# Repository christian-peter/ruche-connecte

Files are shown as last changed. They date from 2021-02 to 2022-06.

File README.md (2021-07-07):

# !!! EN COURS DE REDACTION !!! 
donc incomplet et en évolution à un rythme aléatoire

# Outil de suivi de ruchers
Ce projet est en cours de développement. Tous les éléments décrits dans le synoptique ne sont donc pas fonctionnels à ce jour.

Certains éléments ont été développés par des apprentis ingénieurs suivant la formation "électronique et informatique industrielle" à 
[Polytech Nice Sophia](http://unice.fr/polytechnice/fr). Une page spécifique à ce projet est disponible [ici](http://rucher.polytech.unice.fr/).  

L'objectif consiste à relever différents paramètres (masse, vibrations, température et hygrométrie interne à la ruche, données météorologiques) pour les rendre accessibles à distance via des périphériques tels qu'un ordinateur, une tablette, un smartphone ....  
 
Afin de remplir ces différentes fonctions, le système global à été scindé en plusieurs blocs. Les fonctions des trois premiers modules, qui doivent être autonomes en énergie, sont les suivantes :

* relever la masse de la ruche ;
* mesurer les grandeurs internes (températures, hygrométrie, vibrations, ....) ;
* mesurer les données météorologiques (température, hygrométrie, vent, pluie, ensoleillement, ...).

Les données relevées par ces modules sont transmises via un réseau LoRa, dont la portée doit être importante, à une passerelle dont la fonction consiste à enregistrer ces mesures dans une base de données. Ces données sont alors rendues accessibles via un serveur "web". 

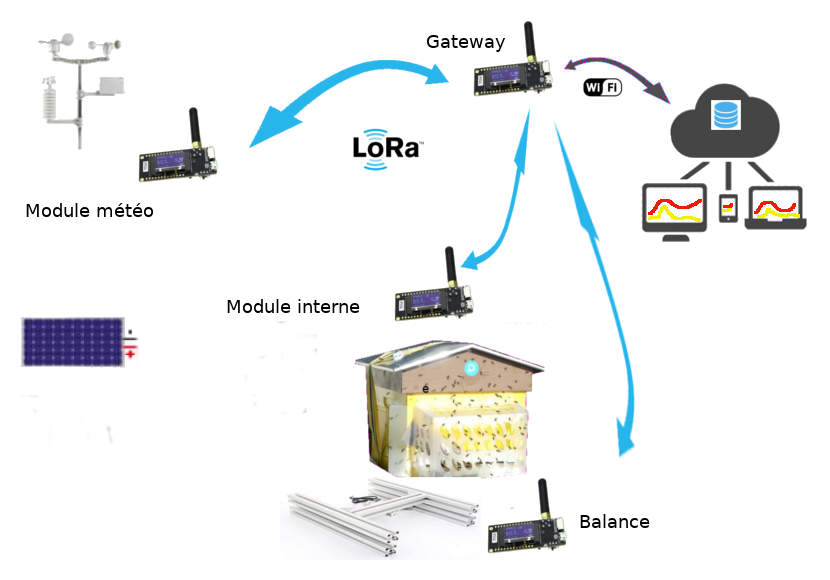
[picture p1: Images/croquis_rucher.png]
synoptique


L'électronique a été développée autour d'un microcontrôleur [ESP32](http://esp32.net/) d'Espressif Systems, basé sur l'architecture Xtensa LX6 de Tensilica, intégrant la gestion du Wi-Fi et du Bluetooth et d'un modem LoRa [RFM95](https://www.hoperf.com/modules/lora/RFM95.html).

Elle a été conçue avec un soucis de polyvalence pour permettre différentes configurations mais aussi pour faciliter les évolutions ou optimisations futures. C'est la cas notamment pour l'alimentation des différents modules.

## L'alimentation des modules

La tension d'alimentation des circuits précités est de 3.3V (maxi 3.6V). Il peuvent donc être alimentés directement par des batteries lithium-fer-phosphate (LiFePO<sub>4</sub>). Afin de pouvoir utiliser également d'autres sources d'énergie (batteries Lipo, Liion, plomb, .... ) les cartes sont équipées d'un régulateur de tension (MIC5239).

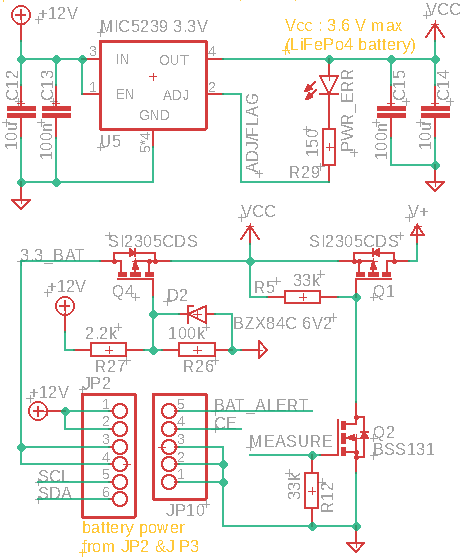
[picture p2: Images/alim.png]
alimentation


Une carte batterie spécifique peut être connectée via les connecteurs JP2 et JP3, elle peut être équipée d'une batterie LiFePO<sub>4</sub> connectée entre la masse et le signal '3.3_BAT'.

En l'absence d'alimentation sur l'entrée '+12V', le transistor Q4 est passant alimentant ainsi les éléments connectés à 'Vcc' à partir de la batterie LiFePO<sub>4</sub>. 

Si la carte est alimentée par l'entrée '+12V', les éléments connectés à 'Vcc' sont alimentés par le régulateur MIC5239. Le transistor Q4 est bloqué car le régulateur ne doit pas charger la batterie. L'entrée '+12V' peut recevoir des tensions comprises entre 3.6V et 30V. 
<!-- Les cartes sont généralement prévues pour recevoir un régulateur en boîtier :

* soit SOT-223,
* soit MSOP.-->

Dans le but d'économiser l'énergie, les périphériques ne sont alimentés par 'V+' que lorsque le transistor Q1 est passant (cad lorsque la sortie 'MEASURE' de l'ESP32 est au niveau haut).

## La programmation du microcontrôleur

Le logiciel est développé sur l'interface arduino. L’installation et l'utilisation de cet outil est décrit
[ici](https://www.arduino-france.com/tutoriels/ide-arduino-installation-et-utilisation/).

Il faut le configurer pour pouvoir utiliser l'ESP32 : voir 
[ce site](http://electroniqueamateur.blogspot.com/2019/07/programmer-lesp32-avec-lide-arduino.html)
ou [celui-ci](http://emery.claude.free.fr/esp32-idearduino.html).

Sauf erreur et/ou oubli, les librairies utilisées sont : 

* [DebugUtils](https://github.com/SensorsIot/DebugUtils/blob/master/DebugUtils/DebugUtils.h)
* [LoRa (Sandeep Mistry)](https://github.com/sandeepmistry/arduino-LoRa)
* [esp8266-oled-ssd1306](https://github.com/ThingPulse/esp8266-oled-ssd1306)
* [SparkFun NAU7802](https://github.com/sparkfun/SparkFun_Qwiic_Scale_NAU7802_Arduino_Library)
* [OneWire](https://www.pjrc.com/teensy/td_libs_OneWire.html)
* [CRC32](https://github.com/bakercp/CRC32)
* [MAX17263-fuel-gauge](https://github.com/avandalen/Arduino-MAX17263-fuel-gauge-library)
* [Streaming](https://github.com/janelia-arduino/Streaming)

Le téléversement nécessite un interface 
[USB/FTDI232](https://www.google.com/search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).

Les connexions minimales à établir sont :

* ESP32 gnd <=> FTDI232 gnd (noir)
* ESP32 Tx <=> FTDI232 Rx (orange)
* ESP32 Rx <=> FTDI232 Tx (jaune)

Si le module n'est pas alimenté de façon autonome, il faut ajouter un fil d'alimentation (Vcc) et le cavalier jaune (voir la flèche) doit être positionné coté 3.3V, si le module dispose de sa propre alimentation il faut retirer le cavalier.

* ESP32 Vcc <=> FTDI232 Vcc (rouge)

Pour activer le mode téléversement il faut : appuyer sur le bouton 'PROG', appuyer et relâcher le bouton 'RST', 
relâcher le bouton 'PROG'.

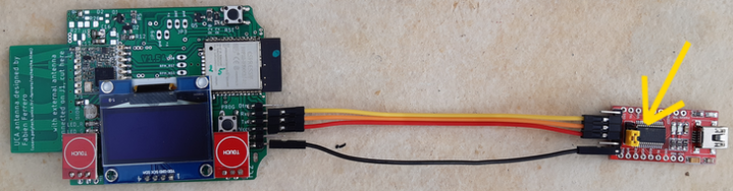
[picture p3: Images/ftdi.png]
ftdi


Pour automatiser le transfert, j'ai développé un 
[petit module](/usb-ftdi232/README.md)
sur lequel on peut souder le module FTDI 232. 
Les connexions sont alors à réaliser sur le circuit secondaire et il faut ajouter :

* ESP32 IO0 <=> FTDI232 IO0 (vert)
* ESP32 RST <=> FTDI232 RST (marron)

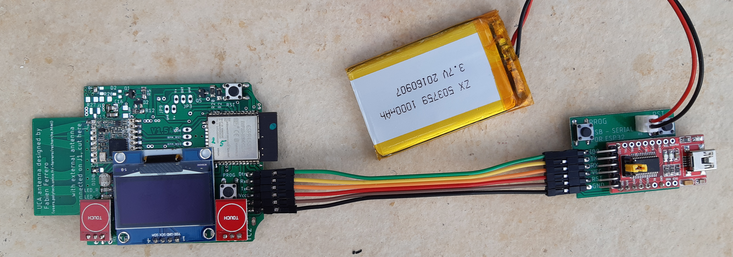
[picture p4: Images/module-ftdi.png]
module-ftdi


Le connecteur JST permet d'alimenter l'ESP32, il faut alors retirer le cavalier d'alimentation.

# La réalisation 

* [la balance](/Balance/README.md#la-balance)
* le module interne
* le module météorologique
* la carte batterie
* la passerelle (gateway)

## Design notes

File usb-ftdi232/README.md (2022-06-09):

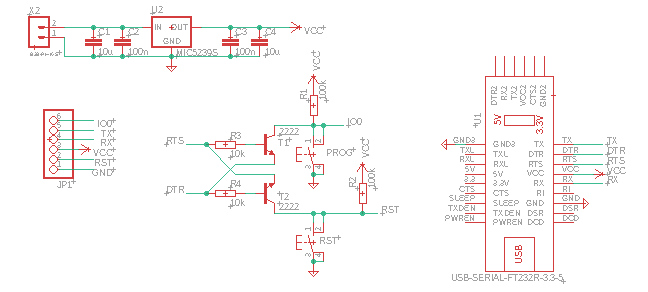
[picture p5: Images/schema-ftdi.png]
schema-ftdi


Les schémas et PCB sont dessinés avec [eagle](https://www.autodesk.com/products/eagle/overview?plc=F360&term=1-YEAR&support=ADVANCED&quantity=1) :

* [schéma](/usb-ftdi232/USB-FTDI-ESP.sch)
* [pcb](/usb-ftdi232/USB-FTDI-ESP.brd)
* [gerber](/usb-ftdi232/gerber/USB-FTDI-ESP32.zip)
* [liste du matériel](/usb-ftdi232/USB-FTDI-ESP.csv)

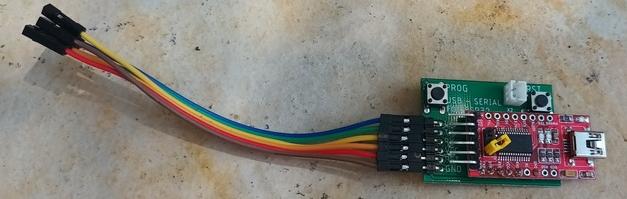
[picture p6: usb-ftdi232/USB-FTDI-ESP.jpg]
image-ftdi


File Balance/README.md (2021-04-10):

# LA BALANCE

## Préambule

Pour la partie mécanique qui ne sera pas développée ici (mis à part quelques photos de prototypes), je me suis inspiré des balances trouvées dans le commerce dont les capteurs de force sont de ce type :

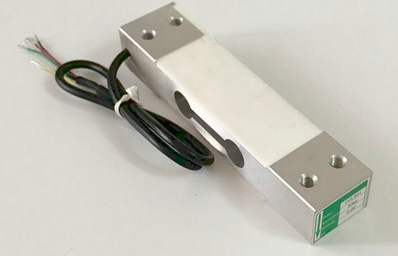
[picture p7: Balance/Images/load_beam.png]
capteur 1


Mon premier prototype avec un capteur n'était pas assez stable à mon gout. J'en ai donc réalisé 
[d'autres](/Balance/Images/proto_meca.png) avec 2 capteurs puis 4 capteurs. 

J'ai aussi testé les capteurs utilisés pour les pèse-personnes.

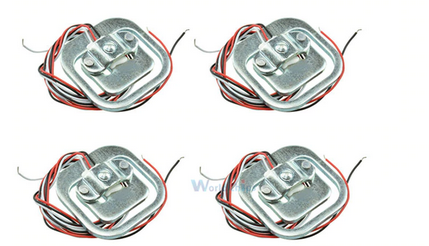
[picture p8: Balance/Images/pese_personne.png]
capteur 2


L'électronique est donc conçue pour s'adapter à ces différentes configurations. 

## Fonctionnement

Après mise sous tension, le module entre en mode sommeil pour réduire la consommation au maximum.
Il se réveille à intervalles réguliers. Il mesure alors la masse et envoie les données (avec un code d'erreur CRC) via un réseau LoRa puis attend un accusé de réception. A réception d'un accusé de réception valide, le module repasse en mode sommeil ; si l'accusé de réception n'est pas valide, les données sont renvoyées (au maximum 'send_max_tries' fois). Sans accusé de réception au bout de 'WAIT_TIME_FOR_ACKNOWLEDGE' le module passe en mode sommeil.

La durée de sommeil est paramétrable et différenciée entre jour et nuit. La période 'jour' débute 1 heure avant le début du jour et s'achève 1 heure après la fin du jour.

Le module peut aussi être réveillé manuellement par un appui bref sur la touche capacitive gauche ; un menu à dérouler avec la touche capacitive droite permet alors de sélectionner différentes actions ou d'afficher différentes informations :

* création d'une visite (dans la base de données),
* mise en sommeil,
* nourrissement 50/50 (1),
* nourrissement 70/30 (1),
* nourrissement candy (1),
* modification matérielle (1),
* mesure de la masse,
* informations batterie,
* informations version et numéro de balance,
* informations LoRa,
* informations température capteurs.

Une fois le choix validé par la touche capacitive gauche, les données sont envoyées ou les informations affichées et le module retourne au mode sommeil.

(1) L'information ainsi que la variation de masse correspondante est stockée dans la base de données.

## Calibration et réglages

Un appui maintenu sur la touche capacitive gauche permet d'accéder à la procédure de calibration ou au réglage des paramètres.

### Calibration

Avant la première utilisation, il faut calibrer la balanceen suivant les indications affichées sur l'écran LCD.

### Réglages

Un certain nombre de paramètres sont modifiables en se connectant au module en Bluetooth avec un terminal série : par exemple 
[Serial Bluetooth Terminal](https://play.google.com/store/apps/details?id=de.kai_morich.serial_bluetooth_terminal&hl=fr&gl=US).

Les paramètres sont regroupés par famille et sont les suivants :

* réglages généraux :
    - intervalle de mesure le jour,
    - intervalle de mesure la nuit,
    - intervalle de mesure pour visite,
    - nombre maximum de transmission,
    - numéro de la balance,
    - variation de masse générant une alerte,
* réglages LoRa :
    - fréquence, 
    - facteur d’étalement de spectre (7 à 12; 12 <=> portée maximale, mais autonomie plus faible),
    - bande passante,
    - puissance d'émission (7 à 15 dB <=> portée maximale, mais autonomie plus faible),
* dérive des capteurs en température,
* initialisation de la mémoire EEPROM (reset des paramètres de calibration et autres réglages).

exemple vidéo : [mp4](http://rucher.polytech.unice.fr/ruche-connecte/videos/reglages.mp4) 
[wmv](http://rucher.polytech.unice.fr/ruche-connecte/videos/reglages.wmv)
<!-- 
ffmpeg -i /tmp/reglages.mp4 -vf scale=960:-1  -an output2.mp4
https://www.linuxtricks.fr/wiki/ffmpeg-la-boite-a-outils-multimedia
https://tuxicoman.jesuislibre.net/2017/01/changer-la-resolution-dune-video-avec-ffmpeg-sous-linux.html
-->

## Electronique

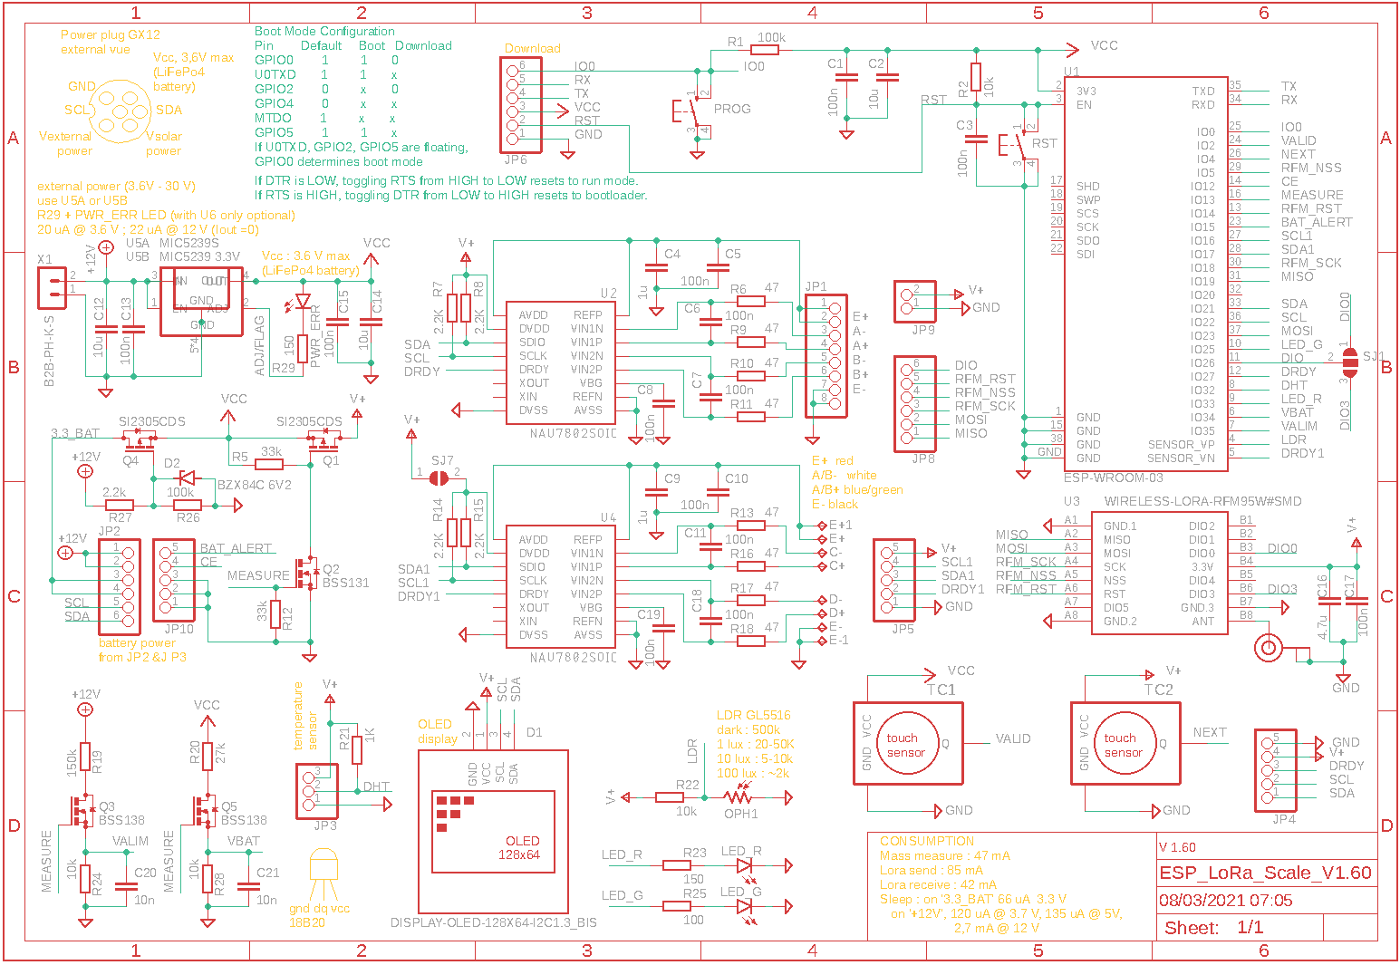
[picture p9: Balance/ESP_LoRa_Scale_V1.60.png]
schema-scale


Les schémas et PCB sont dessinés avec [eagle](https://www.autodesk.com/products/eagle/overview?plc=F360&term=1-YEAR&support=ADVANCED&quantity=1) :

* [schéma](/Balance/ESP_LoRa_Scale_V1.60.sch)
* [pcb](/Balance/ESP_LoRa_Scale_V1.60.brd)
* [gerber](/Balance/gerber/ESP_LoRa_Scale_V1.60.zip)
* [liste du matériel](/Balance/ESP_LoRa_Scale_V1.60.csv)

L'[antenne 'UCA'](http://users.polytech.unice.fr/~ferrero/recherche_UCAboards.html) 
LoRa, déssinée par Fabien Ferrero, est supportée par le circuit imprimé. 
Pour une efficacité maximale de l'antenne, ce dernier doit être réalisé en FR4 avec une épaisseur de 0,8mm.

Il est aussi possible de connecter une antenne externe via un connecteur UFL, la piste reliée à l'antenne 'UCA'
doit alors être coupée.  

pcb-scale


Cette carte peut recevoir 1, 2 ou 4 capteurs de force. Le convertisseur NAU7802 U4 et les composants associés
ne sont utiles que pour l'utilisation de 4 capteurs ; le pont SJ7 doit alors être court-circuité.
Avec 1 ou 2 capteurs on laisse SJ7 ouvert pour réduire la consommation et on utilise les entrées du convertisseur U2.
Un capteur unique doit être connecté sur les entrées 'A', les entrées 'B' étant reliées à la masse.

Le connecteur 'JP3' permet de connecter un capteur de température dans le but de compenser les dérives thermiques des capteurs de force. Pour l'instant seul est supporté le capteur de type 18B20. On pourrait aussi utiliser des capteurs de la famille DHT11,
permettant d'obtenir aussi une mesure d'hygrométrie mais la partie software devra être modifiée en conséquence.

## Logiciel

L'archive est à extraire dans le dossier 'projet' de l'IDE arduino.

* [ESP_LoRa_Scale_V0.34.zip](/Balance/ESP_LoRa_ScaleV0.34.zip)

Hormis la mesure de tension de la batterie, la partie 'fuel gauge' reste à développer.

## Mesures

à venir

## Prototypes

aussi

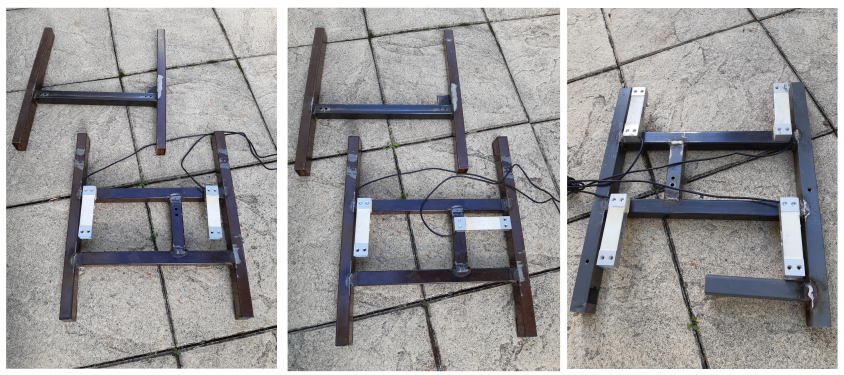
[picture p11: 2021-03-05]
Balance/Images/proto_meca.png

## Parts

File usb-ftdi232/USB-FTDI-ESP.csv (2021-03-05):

Qty | Value | Device | Package | Parts | Description | MF | MPN | OC_FARNELL | OC_NEWARK | POPULARITY | SPICEMODEL | SPICEPREFIX
2 |  | 10-XX | B3F-10XX | PROG, RST | OMRON SWITCH |  | B3F-1000 | 176432 | 36M3542 | 72
1 |  | PINHD-1X6 | 1X06 | JP1 | PIN HEADER |  |  |  |  | 79
2 | 100k | RR1206 | R1206 | R1, R2 | RESISTOR, European symbol |  |  |  |  |  | NONE | R
2 | 100n | C-EUC1206K | C1206K | C2, C3 | CAPACITOR, European symbol |  |  |  |  | 13 |  | C
2 | 10k | RR1206 | R1206 | R3, R4 | RESISTOR, European symbol |  |  |  |  |  | NONE | R
2 | 10u | C-EUC1206K | C1206K | C1, C4 | CAPACITOR, European symbol |  |  |  |  | 13 |  | C
2 | 2222 | MMBT2222ALT1-NPN-SOT23-BEC | SOT23-BEC | T1, T2 | NPN Transistror |  |  |  |  | 0
1 | B2B-PH-K-S | B2B-PH-K-S | B2B-PH-K-S | X2 | JST PH series header 2.00mm pitch disconnectable crimp style connectors, vertical (side entry type), 2 pins
1 | MIC5239S | MIC5239S | SOT223 | U2 | LDO REGULATOR
1 | USB-SERIAL-FT232R-3.3-5 | USB-SERIAL-FT232R-3.3-5 | USB-SERIAL-FT232R-3.3-5 | U1 | USB to Serial UART Converter based on FT232R chip

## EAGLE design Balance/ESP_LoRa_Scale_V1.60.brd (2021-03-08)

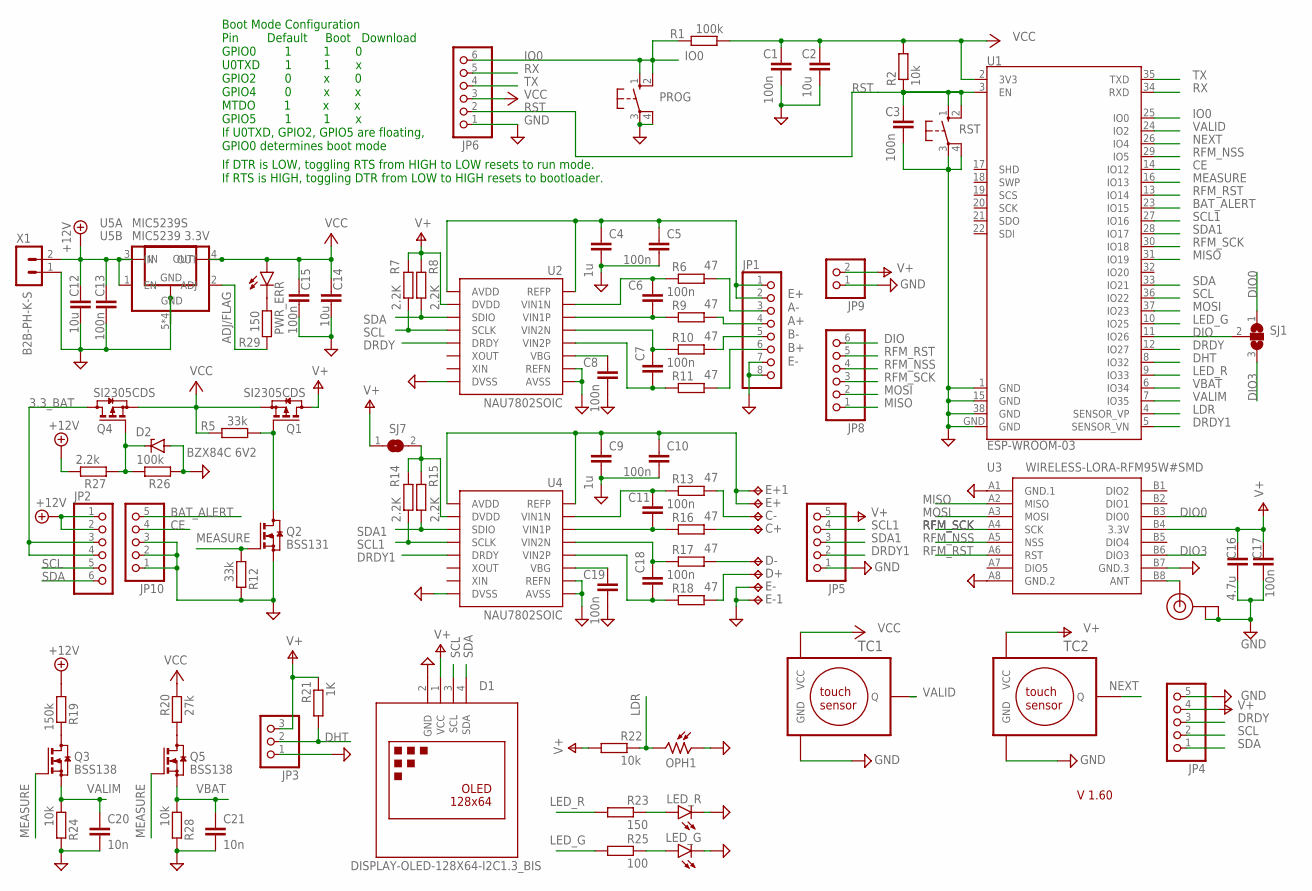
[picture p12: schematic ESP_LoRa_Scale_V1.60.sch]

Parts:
C1, C3, C5, C6, C7, C8, C10, C11, C13, C15, C17, C18, C19: 100n; C1206
C2, C12, C14: 10u; C1210
C4, C9: 1u; C1210
C16: 4.7u; C1210
C20, C21: 10n; C1206
C+: TPTP17SQ; TP17SQ
C-: TPTP17SQ; TP17SQ
D1: DISPLAY-OLED-128X64-I2C1.3_BIS; DISPLAY-OLED-128X64-1.3-I2C_BIS
D2: BZX84C 6V2; TO236
D+: TPTP17SQ; TP17SQ
D-: TPTP17SQ; TP17SQ
E+, E+1: TPTP17SQ; TP17SQ
E-, E-1: TPTP17SQ; TP17SQ
J1: U.FL
JP1: PINHD-1X8; 1X08
JP2, JP6, JP8: PINHD-1X6; 1X06
JP3: PINHD-1X3; 1X03
JP4, JP5, JP10: PINHD-1X5; 1X05
JP9: PINHD-1X2; 1X02
LED_G: LEDSMT1206; 1206
LED_R: LEDSMT1206; 1206
OPH1: VT93N2; VT900
PROG: 10-XX; B3F-10XX
PWR_ERR: LEDSMT1206; 1206
Q1, Q4: SI2305CDS; SOT23
Q2: BSS131; SOT23
Q3, Q5: BSS138; SOT23
R1, R26: 100k; R1206
R2, R22, R24, R28: 10k; R1206
R5, R12: 33k; R1206
R6, R9, R10, R11, R13, R16, R17, R18: 47; R1206
R7, R8, R14, R15: 2.2K; R1206
R19: 150k; R1206
R20: 27k; R1206
R21: 1K; R1206
R23, R29: 150; R1206
R25: 100; R1206
R27: 2.2k; R1206
RST: 10-XX; B3F-10XX
SJ1: SJ2W; SJ_2
SJ7: SJ
TC1, TC2: TTP223R_H; TTP233RED_H
U1: ESP-WROOM-03
U2, U4: NAU7802SOIC; SO16
U3: WIRELESS-LORA-RFM95W#SMD
U5A: MIC5239 3.3V; MSOP08
U5B: MIC5239S; SOT223
X1: B2B-PH-K-S

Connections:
3.3_BAT: JP2.3, JP2.4, Q4.3 (D)
+12V: C12.1, C13.1, JP2.1, JP2.2, R19.1, R27.2, U5A.1 (EN), U5A.3 (IN), U5B.1 (IN), X1.2
A+: JP1.4, R9.2
A-: JP1.3, R6.2
ADJ/FLAG: R29.2, U5A.2 (ADJ)
ANT: J1.3 (SIGNAL), U3.B8 (ANT)
B+: JP1.6, R11.2
B-: JP1.5, R10.2
BAT_ALERT: JP10.5, U1.23 (IO15)
CE: JP10.4, U1.14 (IO12)
DHT: JP3.2, R21.1, U1.8 (IO32)
DIO: JP8.6, SJ1.2, U1.11 (IO26)
DIO0: SJ1.1, U3.B3 (DIO0)
DIO3: SJ1.3, U3.B6 (DIO3)
DRDY: JP4.3, U1.12 (IO27), U2.12 (DRDY)
DRDY1: JP5.2, U1.5 (SENSOR_VN), U4.12 (DRDY)
GND: C1.2, C2.2, C3.2, C4.2, C5.2, C8.2, C9.2, C10.2, C12.2, C13.2, C14.2, C15.2, C16.2, C17.2, C19.2, C20.2, C21.2, D1.2 (GND), D2.A, E-.TP, E-1.TP, J1.1 (GND), J1.2 (GND), JP1.7, JP1.8, JP3.1, JP4.5, JP5.1, JP6.1, JP9.1, JP10.1, JP10.2, JP10.3, LED_G.C, LED_R.C, OPH1.1, PROG.3, PROG.4 (P1), Q2.2 (S), R12.2, R24.2, R26.1, R28.2, RST.3, RST.4 (P1), TC1.P$3 (GND), TC2.P$3 (GND), U1.1 (GND), U1.15 (GND), U1.38 (GND), U1.GND, U2.7 (REFN), U2.8 (AVSS), U2.9 (DVSS), U3.A1 (GND.1), U3.A8 (GND.2), U3.B7 (GND.3), U4.7 (REFN), U4.8 (AVSS), U4.9 (DVSS), U5A.5 (GND), U5A.6 (GND), U5A.7 (GND), U5A.8 (GND), U5B.2 (GND), U5B.4 (GND), X1.1
IO0: JP6.6, PROG.1 (S), PROG.2 (S1), R1.2, U1.25 (IO0)
LDR: OPH1.2, R22.2, U1.4 (SENSOR_VP)
LED_G: R25.1, U1.10 (IO25)
LED_R: R23.1, U1.9 (IO33)
MEASURE: Q2.1 (G), Q3.1 (G), Q5.1 (G), R12.1, U1.16 (IO13)
MISO: JP8.1, U1.31 (IO19), U3.A2 (MISO)
MOSI: JP8.2, U1.37 (IO23), U3.A3 (MOSI)
unnamed: Q1.1 (G), Q2.3 (D), R5.1
unnamed: Q3.3 (D), R19.2
unnamed: R14.2, R15.2, SJ7.2, U4.15 (DVDD)
unnamed: Q5.3 (D), R20.1
unnamed: PWR_ERR.C, R29.1
unnamed: LED_R.A, R23.2
unnamed: LED_G.A, R25.2
unnamed: C8.1, U2.6 (VBG)
unnamed: C19.1, U4.6 (VBG)
unnamed: C11.2, R16.1, U4.3 (VIN1P)
unnamed: C11.1, R13.1, U4.2 (VIN1N)
unnamed: C6.2, R9.1, U2.3 (VIN1P)
unnamed: C6.1, R6.1, U2.2 (VIN1N)
unnamed: C7.1, R10.1, U2.4 (VIN2N)
unnamed: C7.2, R11.1, U2.5 (VIN2P)
unnamed: C18.1, R17.1, U4.4 (VIN2N)
unnamed: C18.2, R18.1, U4.5 (VIN2P)
unnamed: D+.TP, R18.2
unnamed: D-.TP, R17.2
unnamed: C9.1, C10.1, E+.TP, E+1.TP, U4.1 (REFP), U4.16 (AVDD)
unnamed: C-.TP, R13.2
unnamed: C+.TP, R16.2
unnamed: C4.1, C5.1, JP1.1, JP1.2, U2.1 (REFP), U2.16 (AVDD)
unnamed: D2.C, Q4.1 (G), R26.2, R27.1
NEXT: TC2.P$2 (Q), U1.26 (IO4)
RFM_NSS: JP8.4, U1.29 (IO5), U3.A5 (NSS)
RFM_RST: JP8.5, U1.13 (IO14), U3.A6 (RST)
RFM_SCK: JP8.3, U1.30 (IO18), U3.A4 (SCK)
RST: C3.1, JP6.2, R2.1, RST.1 (S), RST.2 (S1), U1.3 (EN)
RX: JP6.5, U1.34 (RXD)
SCL: D1.3 (SCL), JP2.5, JP4.2, R7.1, U1.36 (IO22), U2.13 (SCLK)
SCL1: JP5.4, R14.1, U1.27 (IO16), U4.13 (SCLK)
SDA: D1.4 (SDA), JP2.6, JP4.1, R8.1, U1.33 (IO21), U2.14 (SDIO)
SDA1: JP5.3, R15.1, U1.28 (IO17), U4.14 (SDIO)
TX: JP6.4, U1.35 (TXD)
V+: C16.1, C17.1, D1.1 (VCC), JP3.3, JP4.4, JP5.5, JP9.2, Q1.3 (D), R7.2, R8.2, R21.2, R22.1, SJ7.1, TC2.P$1 (VCC), U2.15 (DVDD), U3.B4 (3.3V)
VALID: TC1.P$2 (Q), U1.24 (IO2)
VALIM: C20.1, Q3.2 (S), R24.1, U1.7 (IO35)
VBAT: C21.1, Q5.2 (S), R28.1, U1.6 (IO34)
VCC: C1.1, C2.1, C14.1, C15.1, JP6.3, PWR_ERR.A, Q1.2 (S), Q4.2 (S), R1.1, R2.2, R5.2, R20.2, TC1.P$1 (VCC), U1.2 (3V3), U5A.4 (OUT), U5B.3 (OUT)

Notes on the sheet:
If DTR is LOW, toggling RTS from HIGH to LOW resets to run mode. If RTS is HIGH, toggling DTR from LOW to HIGH resets to bootloader.
Boot Mode Configuration Pin Default Boot Download GPIO0 1 1 0 U0TXD 1 1 x GPIO2 0 x 0 GPIO4 0 x x MTDO 1 x x GPIO5 1 1 x If U0TXD, GPIO2, GPIO5 are floating, GPIO0 determines boot mode
V 1.60
E+ A- A+ B- B+ E-

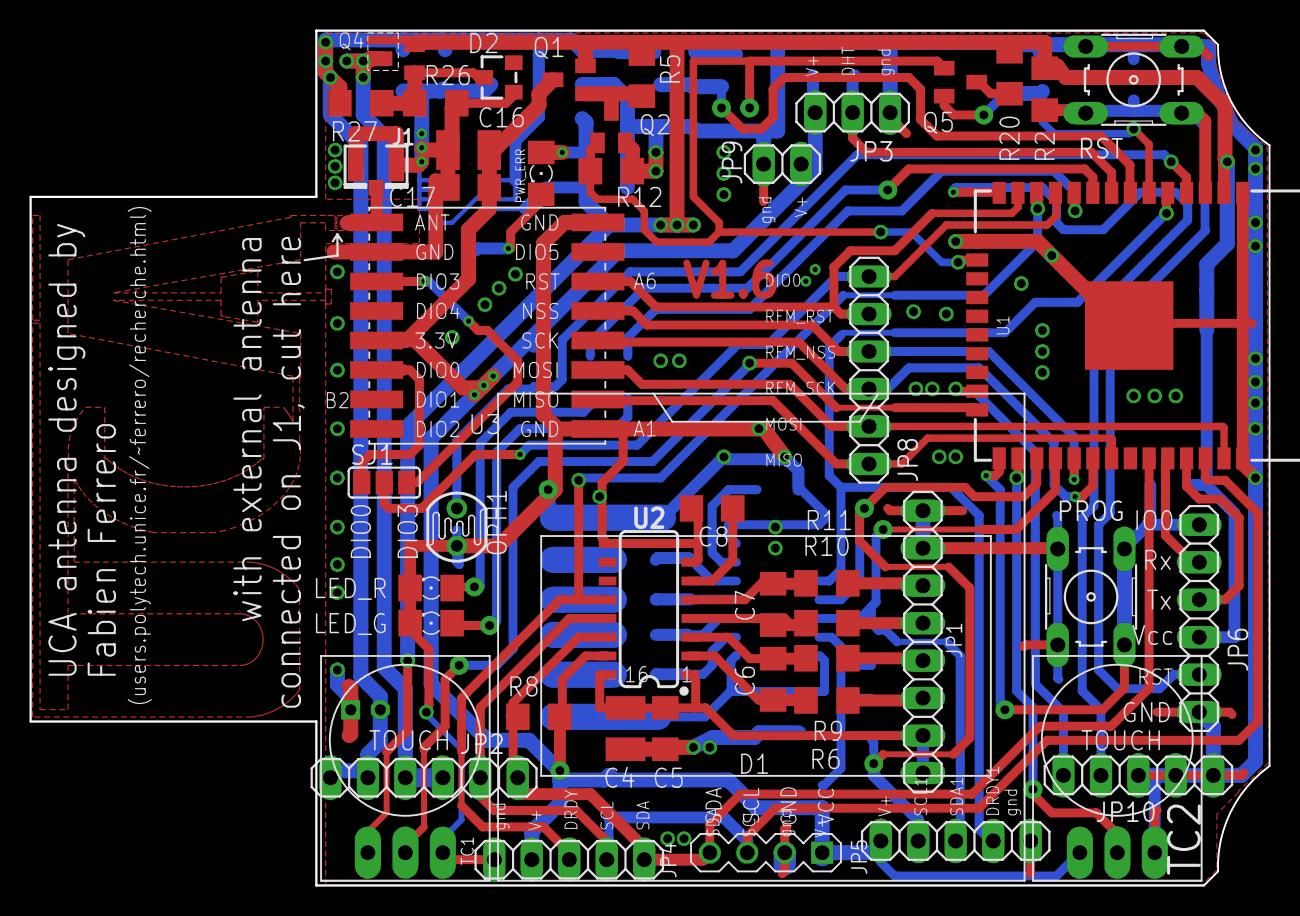
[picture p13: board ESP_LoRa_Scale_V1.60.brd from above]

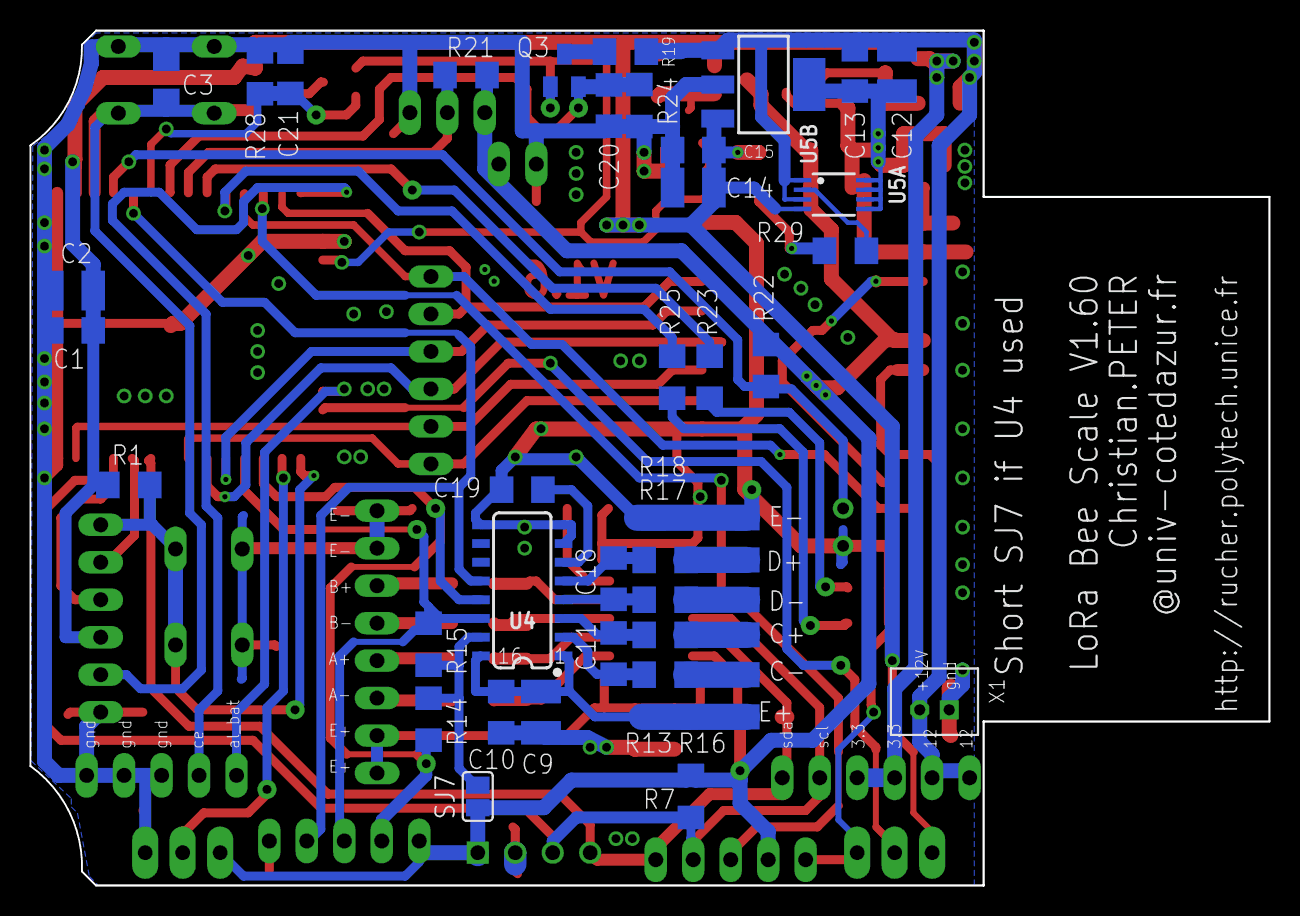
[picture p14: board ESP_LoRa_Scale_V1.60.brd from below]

Board: 2 copper layers, 84.0 x 57.9 mm, 90 parts (44 on the bottom side), 64 nets.

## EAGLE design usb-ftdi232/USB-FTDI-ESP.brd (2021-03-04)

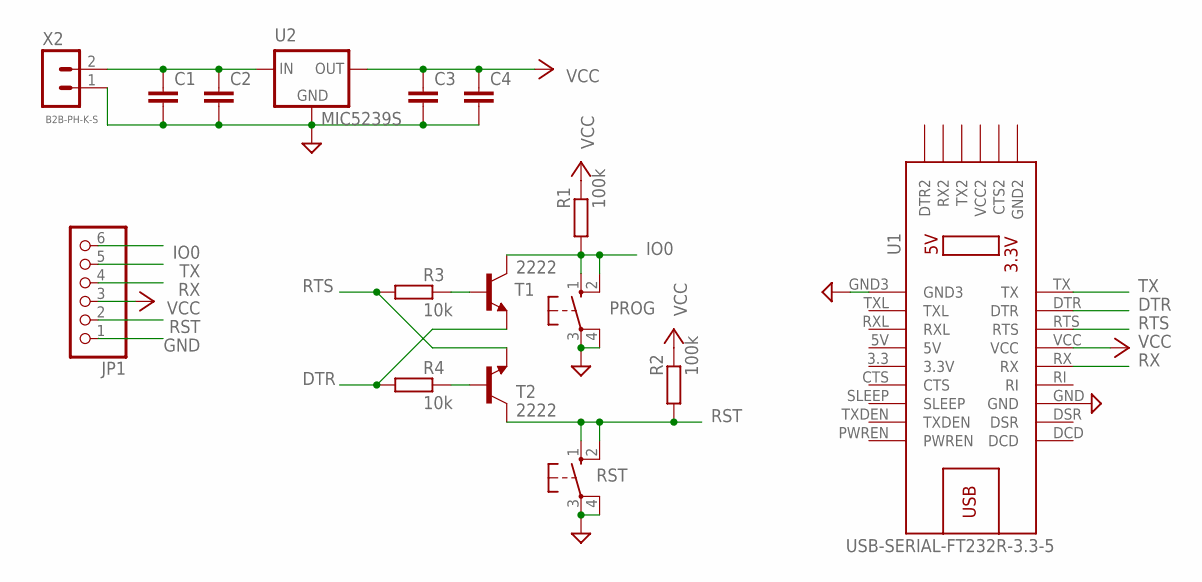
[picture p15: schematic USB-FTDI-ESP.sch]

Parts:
C1, C2, C3, C4: C-EUC1206K; C1206K
JP1: PINHD-1X6; 1X06
PROG: 10-XX; B3F-10XX
R1, R2: 100k; R1206
R3, R4: 10k; R1206
RST: 10-XX; B3F-10XX
T1, T2: 2222; SOT23-BEC
U1: USB-SERIAL-FT232R-3.3-5
U2: MIC5239S; SOT223
X2: B2B-PH-K-S

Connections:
DTR: R4.1, T1.E, U1.DTR
GND: C1.2, C2.2, C3.2, C4.2, JP1.1, PROG.3, PROG.4 (P1), RST.3, RST.4 (P1), U1.GND, U1.GND3, U2.2 (GND), U2.4 (GND), X2.1
IO0: JP1.6, PROG.1 (S), PROG.2 (S1), R1.1, T1.C
unnamed: C1.1, C2.1, U2.1 (IN), X2.2
unnamed: R3.2, T1.B
unnamed: R4.2, T2.B
RST: JP1.2, R2.1, RST.1 (S), RST.2 (S1), T2.C
RTS: R3.1, T2.E, U1.RTS
RX: JP1.4, U1.RX
TX: JP1.5, U1.TX
VCC: C3.1, C4.1, JP1.3, R1.2, R2.2, U1.VCC, U2.3 (OUT)
VCC2: U1.VCC2

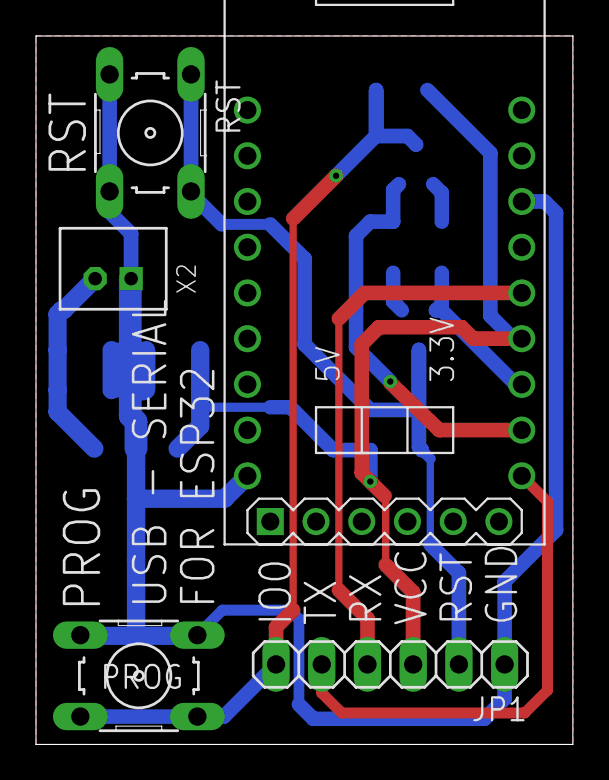
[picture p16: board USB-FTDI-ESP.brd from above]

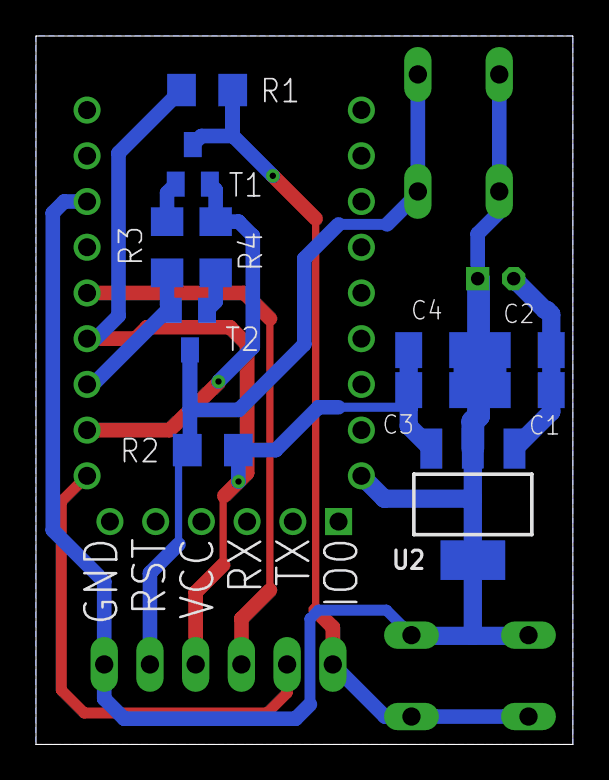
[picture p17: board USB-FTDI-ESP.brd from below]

Board: 2 copper layers, 29.8 x 39.4 mm, 16 parts (11 on the bottom side), 11 nets.

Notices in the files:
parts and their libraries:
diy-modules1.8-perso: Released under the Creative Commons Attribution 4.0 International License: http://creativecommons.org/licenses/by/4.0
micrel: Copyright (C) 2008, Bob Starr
